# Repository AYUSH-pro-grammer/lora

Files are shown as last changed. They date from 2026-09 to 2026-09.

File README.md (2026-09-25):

# Lora

A LoRa board project that I made in order to figure out how radios really work, rather than just reading about them. It was a great way for me to do some PCB design and play around with KiCad, while learning what to do when things don’t go according to plan (which happened quite a bit).

# How its works

This board is a custom designed wireless communication module for long range applications. It is based on the dual-core Raspberry Pi RP2040 microcontroller and SX1262 LoRa transceiver.

- Power & Connectivity. 5V power and data thru USB-C port. An AP2112K-3.3 LDO regulator efficiently steps this down to a stable 3.3V for the system.

- Processing & Memory - The RP2040 is the brain. The RP2040 requires external memory, so it’s coupled with a W25Q16JV SPI Flash chip to store your firmware.

- Long-Range RF The SX1262 provides sub-GHz LoRa wireless communication. The RF path is controlled by a PE4259 RF switch and a Johanson Balun to condition the signal for the antenna.

- Internal Routing: The RP2040 uses its SPI busses to talk to the Flash memory and the SX1262 LoRa chip.

```text
[ USB-C ] ──5V──► [ AP2112K-3.3 LDO ] ──3.3V──┐
                                              ▼
[ W25Q16 Flash ] ◄──SPI── [ RP2040 ] ──SPI──► [ SX1262 LoRa ]
                        (Main Brain)                │
                                                    ▼
                                            [ PE4259 Switch ]
                                                    │
                                                    ▼
                                                [ Antenna ]
                                                    📡

```

# Images:

## 3d

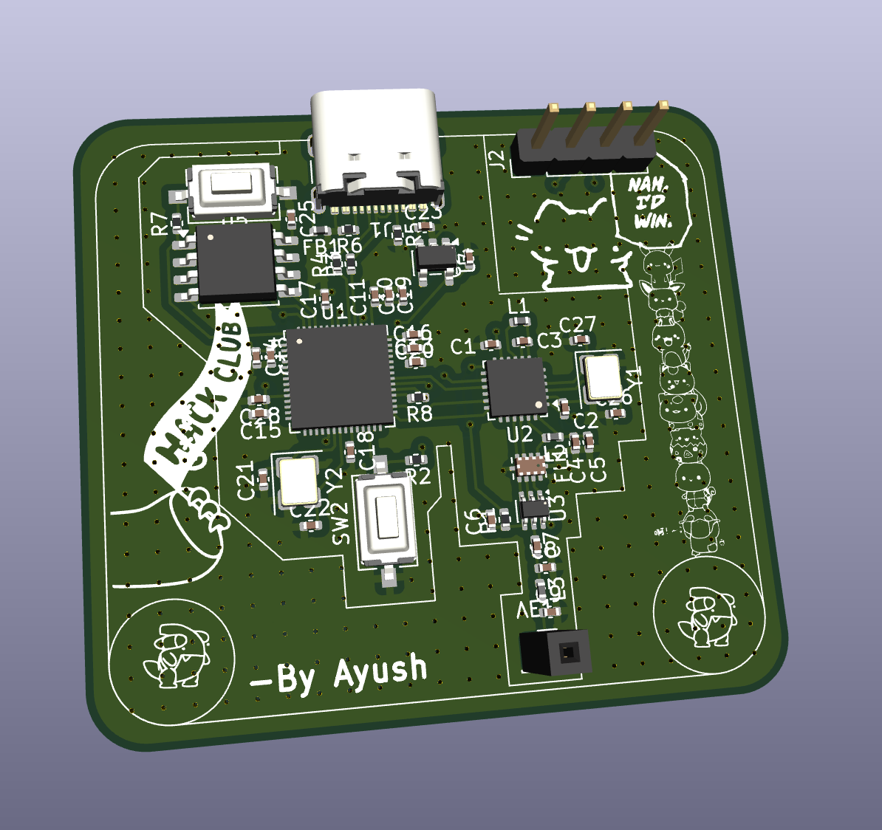
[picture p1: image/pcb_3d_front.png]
PCB 3D Front


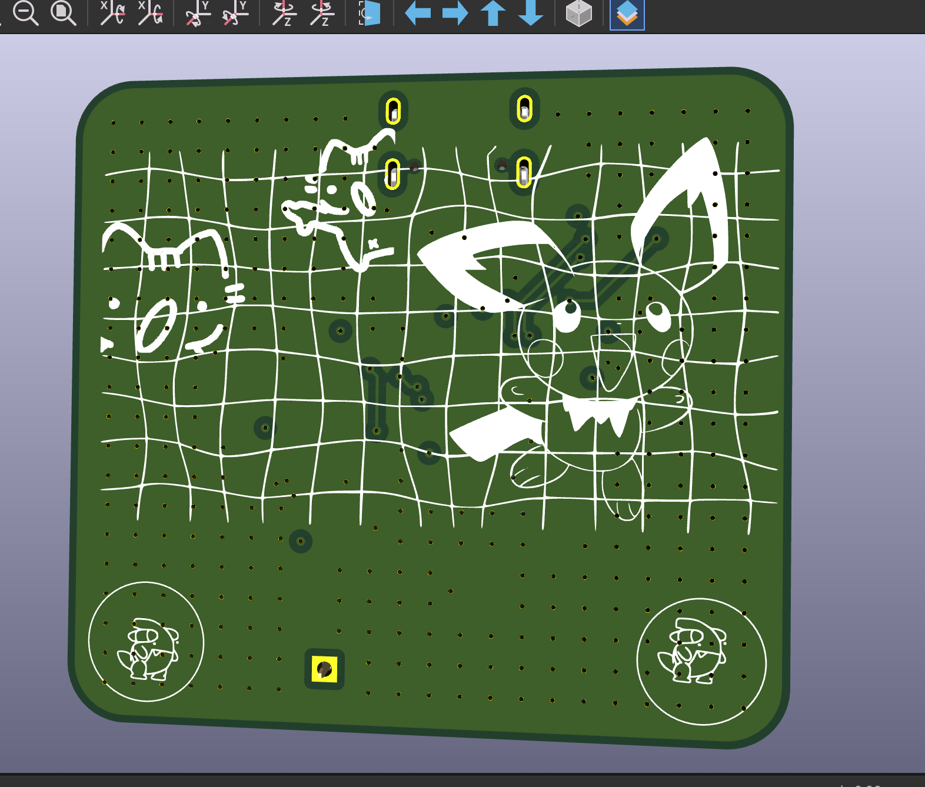
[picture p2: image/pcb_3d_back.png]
PCB 3D Back


## Schematic

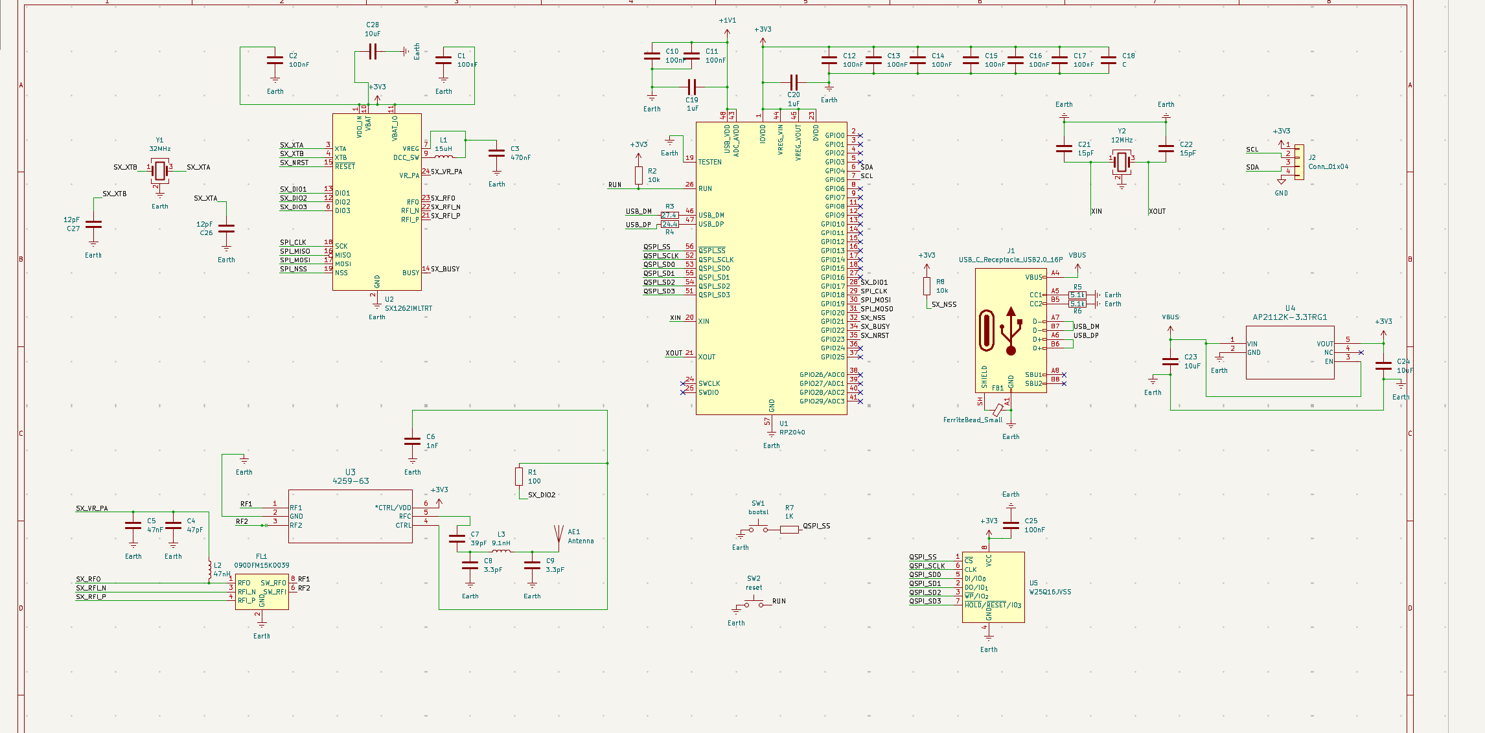
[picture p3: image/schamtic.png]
Schematic


## PCB 

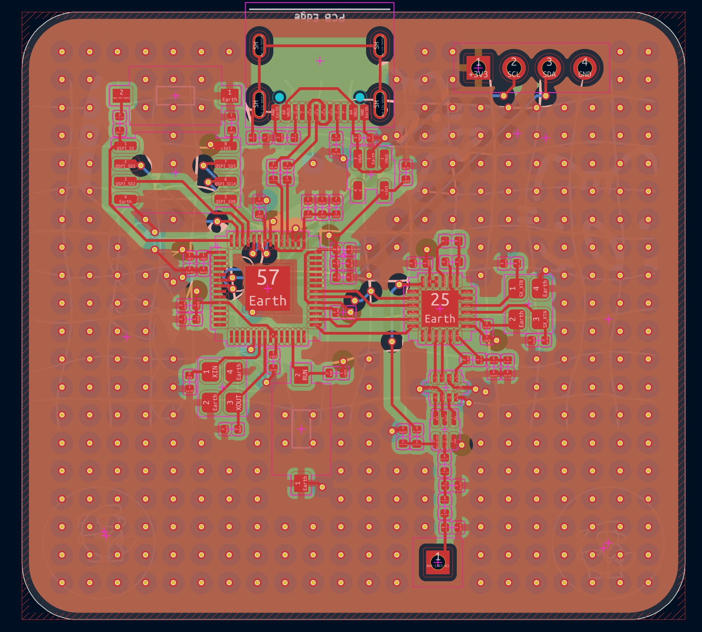
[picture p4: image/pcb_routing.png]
PCB Routing


## Components

Total Physical Components: 53
Capacitors: 28
Resistors: 8
Inductors: 3
Crystals/Oscillators: 2
Push Buttons (Cherry MX): 2
Antenna / Pin Headers: 2 (1 Spring Antenna + 1 Pin Header)
Ferrite Beads: 1
RF Baluns: 1
USB-C Connectors: 1
Voltage Regulators (AP2112K): 1
RF Switches (PE4259): 1
Flash Memory (W25Q16JV): 1
SX1262 LoRa IC: 1
RP2040 Microcontroller: 1

## BOM

|  Qty  | Component | Selected Part | Supplier  | Link | MOQ | Unit Price (USD) | Order Cost (USD) |
| :---: | :--- | :--- | :--- | :--- | --: | ---: | ---: |
| 1 | LoRa Spring Antenna | BW915SNX17-5W2 | LCSC | [Link](https://www.lcsc.com/product-detail/C496556.html) | 5 | $0.165 | $0.83 |
| 1 | Antenna Pin Header | 2.54-1×40P Pin Header | LCSC | [Link](https://www.lcsc.com/product-detail/C2337.html) | 5 | $0.159 | $0.80 |
| 12  | 100 nF Capacitor | 100 nF 16 V 0402 X7R | LCSC | [Link](https://www.lcsc.com/product-detail/C1525.html) | 100 | $0.005 | $0.46 |
| 1 | 150 pF Capacitor | 150 pF 50 V 0402 X7R | LCSC | [Link](https://www.lcsc.com/product-detail/C1527.html) | 100 | $0.004 | $0.43 |
| 1 | 20 pF Capacitor | 20 pF 50 V 0402 C0G | LCSC | [Link](https://www.lcsc.com/product-detail/C1554.html) | 100 | $0.007 | $0.69 |
| 1 | 220 pF Capacitor | 220 pF 50 V 0402 X7R | LCSC | [Link](https://www.lcsc.com/product-detail/C1530.html) | 100 | $0.003 | $0.25 |
| 1 | 1.8 pF Capacitor | 1.8 pF 50 V 0402 C0G | LCSC | [Link](https://www.lcsc.com/product-detail/C1553.html) | 100 | $0.005 | $0.50 |
| 2 | 15 pF Capacitor | 15 pF 50 V 0402 C0G | LCSC | [Link](https://www.lcsc.com/product-detail/C1548.html) | 100 | $0.004 | $0.36 |
| 2 | 12 pF Capacitor | 12 pF 50 V 0402 C0G | LCSC | [Link](https://www.lcsc.com/product-detail/C1547.html) | 100 | $0.006 | $0.60 |
| 2 | 1 pF Capacitor | 1 pF 50 V 0402 C0G | LCSC | [Link](https://www.lcsc.com/product-detail/C1550.html) | 100 | $0.003 | $0.27 |
| 3 | 160 pF Capacitor | 160 pF 50 V 0402 X7R | LCSC | [Link](https://www.lcsc.com/product-detail/C1528.html) | 100 | $0.005 | $0.51 |
| 2 | 1 µF Capacitor | 1 µF 16 V 0402 X5R | LCSC | [Link](https://www.lcsc.com/product-detail/C167339.html) |  50 | $0.015 | $0.73 |
| 1 | 1 nF Capacitor | 1 nF 50 V 0402 X7R | LCSC | [Link](https://www.lcsc.com/product-detail/C1523.html) | 100 | $0.005 | $0.51 |
| 1 | Ferrite Bead | 100 Ω @ 100 MHz 0402 | LCSC | [Link](https://www.lcsc.com/product-detail/C280601.html) |  20 | $0.006 | $0.12 |
| 1 | RF Balun | 0900FM15D0039E | LCSC | [Link](https://www.lcsc.com/product-detail/C1513363.html) | 1 | $1.214 | $1.21 |
| 1 | USB Type-C Connector | TYPE-C 16PIN SMD | LCSC | [Link](https://www.lcsc.com/product-detail/C2765186.html) |  20 | $0.071 | $1.43 |
| 1 | 15 nH Inductor | 15 nH ±3% 0402 | LCSC | [Link](https://www.lcsc.com/product-detail/C329619.html) |  10 | $0.041 | $0.41 |
| 1 | 47 nH Inductor | 47 nH ±2% 0402 | LCSC | [Link](https://www.lcsc.com/product-detail/C22334.html) |  10 | $0.064 | $0.64 |
| 1 | 9.1 nH Inductor | 9.1 nH ±2% 0402 | LCSC | [Link](https://www.lcsc.com/product-detail/C7516935.html) | 1 | $0.095 | $0.09 |
| 1 | 100 Ω Resistor | 100 Ω ±1% 0402 | LCSC | [Link](https://www.lcsc.com/product-detail/C25076.html) | 100 | $0.004 | $0.37 |
| 2 | 10 kΩ Resistor | 10 kΩ ±1% 0402 | LCSC | [Link](https://www.lcsc.com/product-detail/C25744.html) | 100 | $0.003 | $0.31 |
| 1 | 150 Ω Resistor | 150 Ω ±1% 0402 | LCSC | [Link](https://www.lcsc.com/product-detail/C25082.html) | 100 | $0.002 | $0.19 |
| 1 | 140 Ω Resistor | 140 Ω ±1% 0402 | LCSC | [Link](https://www.lcsc.com/product-detail/C25081.html) | 100 | $0.002 | $0.20 |
| 2 | 5.1 kΩ Resistor | 5.1 kΩ ±1% 0402 | LCSC | [Link](https://www.lcsc.com/product-detail/C25905.html) | 100 | $0.002 | $0.23 |
| 1 | 2.2 kΩ Resistor | 2.2 kΩ ±1% 0402 | LCSC | [Link](https://www.lcsc.com/product-detail/C25879.html) | 100 | $0.004 | $0.35 |
| 1 | Microcontroller | RP2040 (QFN-56) | LCSC | [Link](https://www.lcsc.com/product-detail/C2040.html) | 1 | $0.997 | $1.00 |
| 1 | LoRa Transceiver | SX1262IMLTRT (QFN-24) | LCSC | [Link](https://www.lcsc.com/product-detail/C191341.html) | 1 | $3.222 | $3.22 |
| 1 | RF Switch / LDO | LM337BTG | LCSC | [Link](https://www.lcsc.com/product-detail/C74415.html) | 1 | $0.673 | $0.67 |
| 1 | 3.3 V LDO Regulator | AP2112K-3.3TRG1 | LCSC | [Link](https://www.lcsc.com/product-detail/C51118.html) | 5 | $0.173 | $0.86 |
| 1 | SPI Flash Memory | W25Q16JVSSIQ (SOIC-8) | LCSC | [Link](https://www.lcsc.com/product-detail/C82317.html) | 1 | $1.023 | $1.02 |
| 1 | 32 MHz Crystal | X322532MMB4SI | LCSC | [Link](https://www.lcsc.com/product-detail/C113671.html) | 5 | $0.108 | $0.54 |
| 1 | 12 MHz Crystal | X322512MSB4SI | LCSC | [Link](https://www.lcsc.com/product-detail/C9002.html) | 5 | $0.096 | $0.48 |
| 2 | Tactile Switch | Cherry MX Clear (Pack of 10)  | StacksKB  | [Link](https://stackskb.com/store/cherry-mx-clear-switch-5-pin-pack-of-10/) |  10 | $0.480 | $4.80 |
| 1 | OLED Display | 0.96 Inch OLED Display Module | RoboCraze | [Link](https://robocraze.com/products/0-96in-oled-display-module-4pin) | 1 | $1.74 | $1.74 |
| **—** | **Total Procurement Cost (1st Batch Order)** | | | | | | **~$26.82** |

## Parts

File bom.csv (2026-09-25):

Quantity | Part Name | Link | Unit Price (USD) | Order Cost (USD)
1 | LoRa Spring Antenna BW915SNX17-5W2 (915MHz) | https://www.lcsc.com/product-detail/C496556.html | $0.165 | $0.83
1 | Antenna Pin (2.54mm Vertical Pin Header) | https://www.lcsc.com/product-detail/C2337.html | $0.159 | $0.80
11 | 100nF 16V 0402 Ceramic Capacitor | https://www.lcsc.com/product-detail/C1525.html | $0.005 | $0.46
1 | 150pF 50V 0402 Ceramic Capacitor | https://www.lcsc.com/product-detail/C1527.html | $0.004 | $0.43
1 | 20pF 50V 0402 Ceramic Capacitor | https://www.lcsc.com/product-detail/C1554.html | $0.007 | $0.69
1 | 220pF 50V 0402 Ceramic Capacitor | https://www.lcsc.com/product-detail/C1530.html | $0.003 | $0.25
1 | 1nF 50V 0402 Ceramic Capacitor | https://www.lcsc.com/product-detail/C1523.html | $0.005 | $0.51
1 | 1.8pF 50V 0402 Ceramic Capacitor | https://www.lcsc.com/product-detail/C1553.html | $0.005 | $0.50
2 | 15pF 50V 0402 Ceramic Capacitor | https://www.lcsc.com/product-detail/C1548.html | $0.004 | $0.36
1 | Capacitor C18 (Placeholder 100nF 0402) | https://www.lcsc.com/product-detail/C1525.html | $0.005 | $0.00
2 | 1uF 16V 0402 Ceramic Capacitor | https://www.lcsc.com/product-detail/C167339.html | $0.015 | $0.73
2 | 1pF 50V 0402 Ceramic Capacitor | https://www.lcsc.com/product-detail/C1550.html | $0.003 | $0.27
2 | 12pF 50V 0402 Ceramic Capacitor | https://www.lcsc.com/product-detail/C1547.html | $0.006 | $0.60
3 | 160pF 50V 0402 Ceramic Capacitor | https://www.lcsc.com/product-detail/C1528.html | $0.005 | $0.51
1 | 100 Ohm 0402 Ferrite Bead | https://www.lcsc.com/product-detail/C280601.html | $0.006 | $0.12
1 | Johanson 0900FM15D0039E RF Balun | https://www.lcsc.com/product-detail/C1513363.html | $1.214 | $1.21
1 | USB Type-C 16-Pin Connector (SHOU HAN) | https://www.lcsc.com/product-detail/C2765186.html | $0.071 | $1.43
1 | 15nH 0402 SMD Inductor | https://www.lcsc.com/product-detail/C329619.html | $0.041 | $0.41
1 | 47nH 0402 SMD Inductor | https://www.lcsc.com/product-detail/C22334.html | $0.064 | $0.64
1 | 9.1nH 0402 SMD Inductor | https://www.lcsc.com/product-detail/C7516935.html | $0.095 | $0.09
1 | 100 Ohm 1% 0402 Resistor | https://www.lcsc.com/product-detail/C25076.html | $0.004 | $0.37
2 | 10k Ohm 1% 0402 Resistor | https://www.lcsc.com/product-detail/C25744.html | $0.003 | $0.31
1 | 150 Ohm 1% 0402 Resistor | https://www.lcsc.com/product-detail/C25082.html | $0.002 | $0.19
1 | 140 Ohm 1% 0402 Resistor | https://www.lcsc.com/product-detail/C25081.html | $0.002 | $0.20
2 | 5.1k Ohm 1% 0402 Resistor | https://www.lcsc.com/product-detail/C25905.html | $0.002 | $0.23
1 | 2.2k Ohm 1% 0402 Resistor | https://www.lcsc.com/product-detail/C25879.html | $0.004 | $0.35
2 | Cherry MX Clear Tactile Switch (5-pin) | https://stackskb.com/store/cherry-mx-clear-switch-5-pin-pack-of-10/ | $0.480 | $4.80
1 | RP2040 Microcontroller | https://www.lcsc.com/product-detail/C2040.html | $0.997 | $1.00
1 | SX1262IMLTRT LoRa Transceiver | https://www.lcsc.com/product-detail/C191341.html | $3.222 | $3.22
1 | PE4259-63 RF Switch (SOT-363) | https://www.lcsc.com/product-detail/C74415.html | $0.673 | $0.67
1 | AP2112K-3.3TRG1 LDO Regulator | https://www.lcsc.com/product-detail/C51118.html | $0.173 | $0.86
1 | W25Q16JVSSIQ SPI Flash Memory | https://www.lcsc.com/product-detail/C82317.html | $1.023 | $1.02
1 | 32MHz 3225 4-pin SMD Crystal | https://www.lcsc.com/product-detail/C113671.html | $0.108 | $0.54
1 | 12MHz 3225 4-pin SMD Crystal (RP2040 Target) | https://www.lcsc.com/product-detail/C9002.html | $0.096 | $0.48$
1 | 0.96 Inch OLED Display Module | https://robocraze.com/products/0-96in-oled-display-module-4pin?variant=40192586645657 | $1.74 | $1.74

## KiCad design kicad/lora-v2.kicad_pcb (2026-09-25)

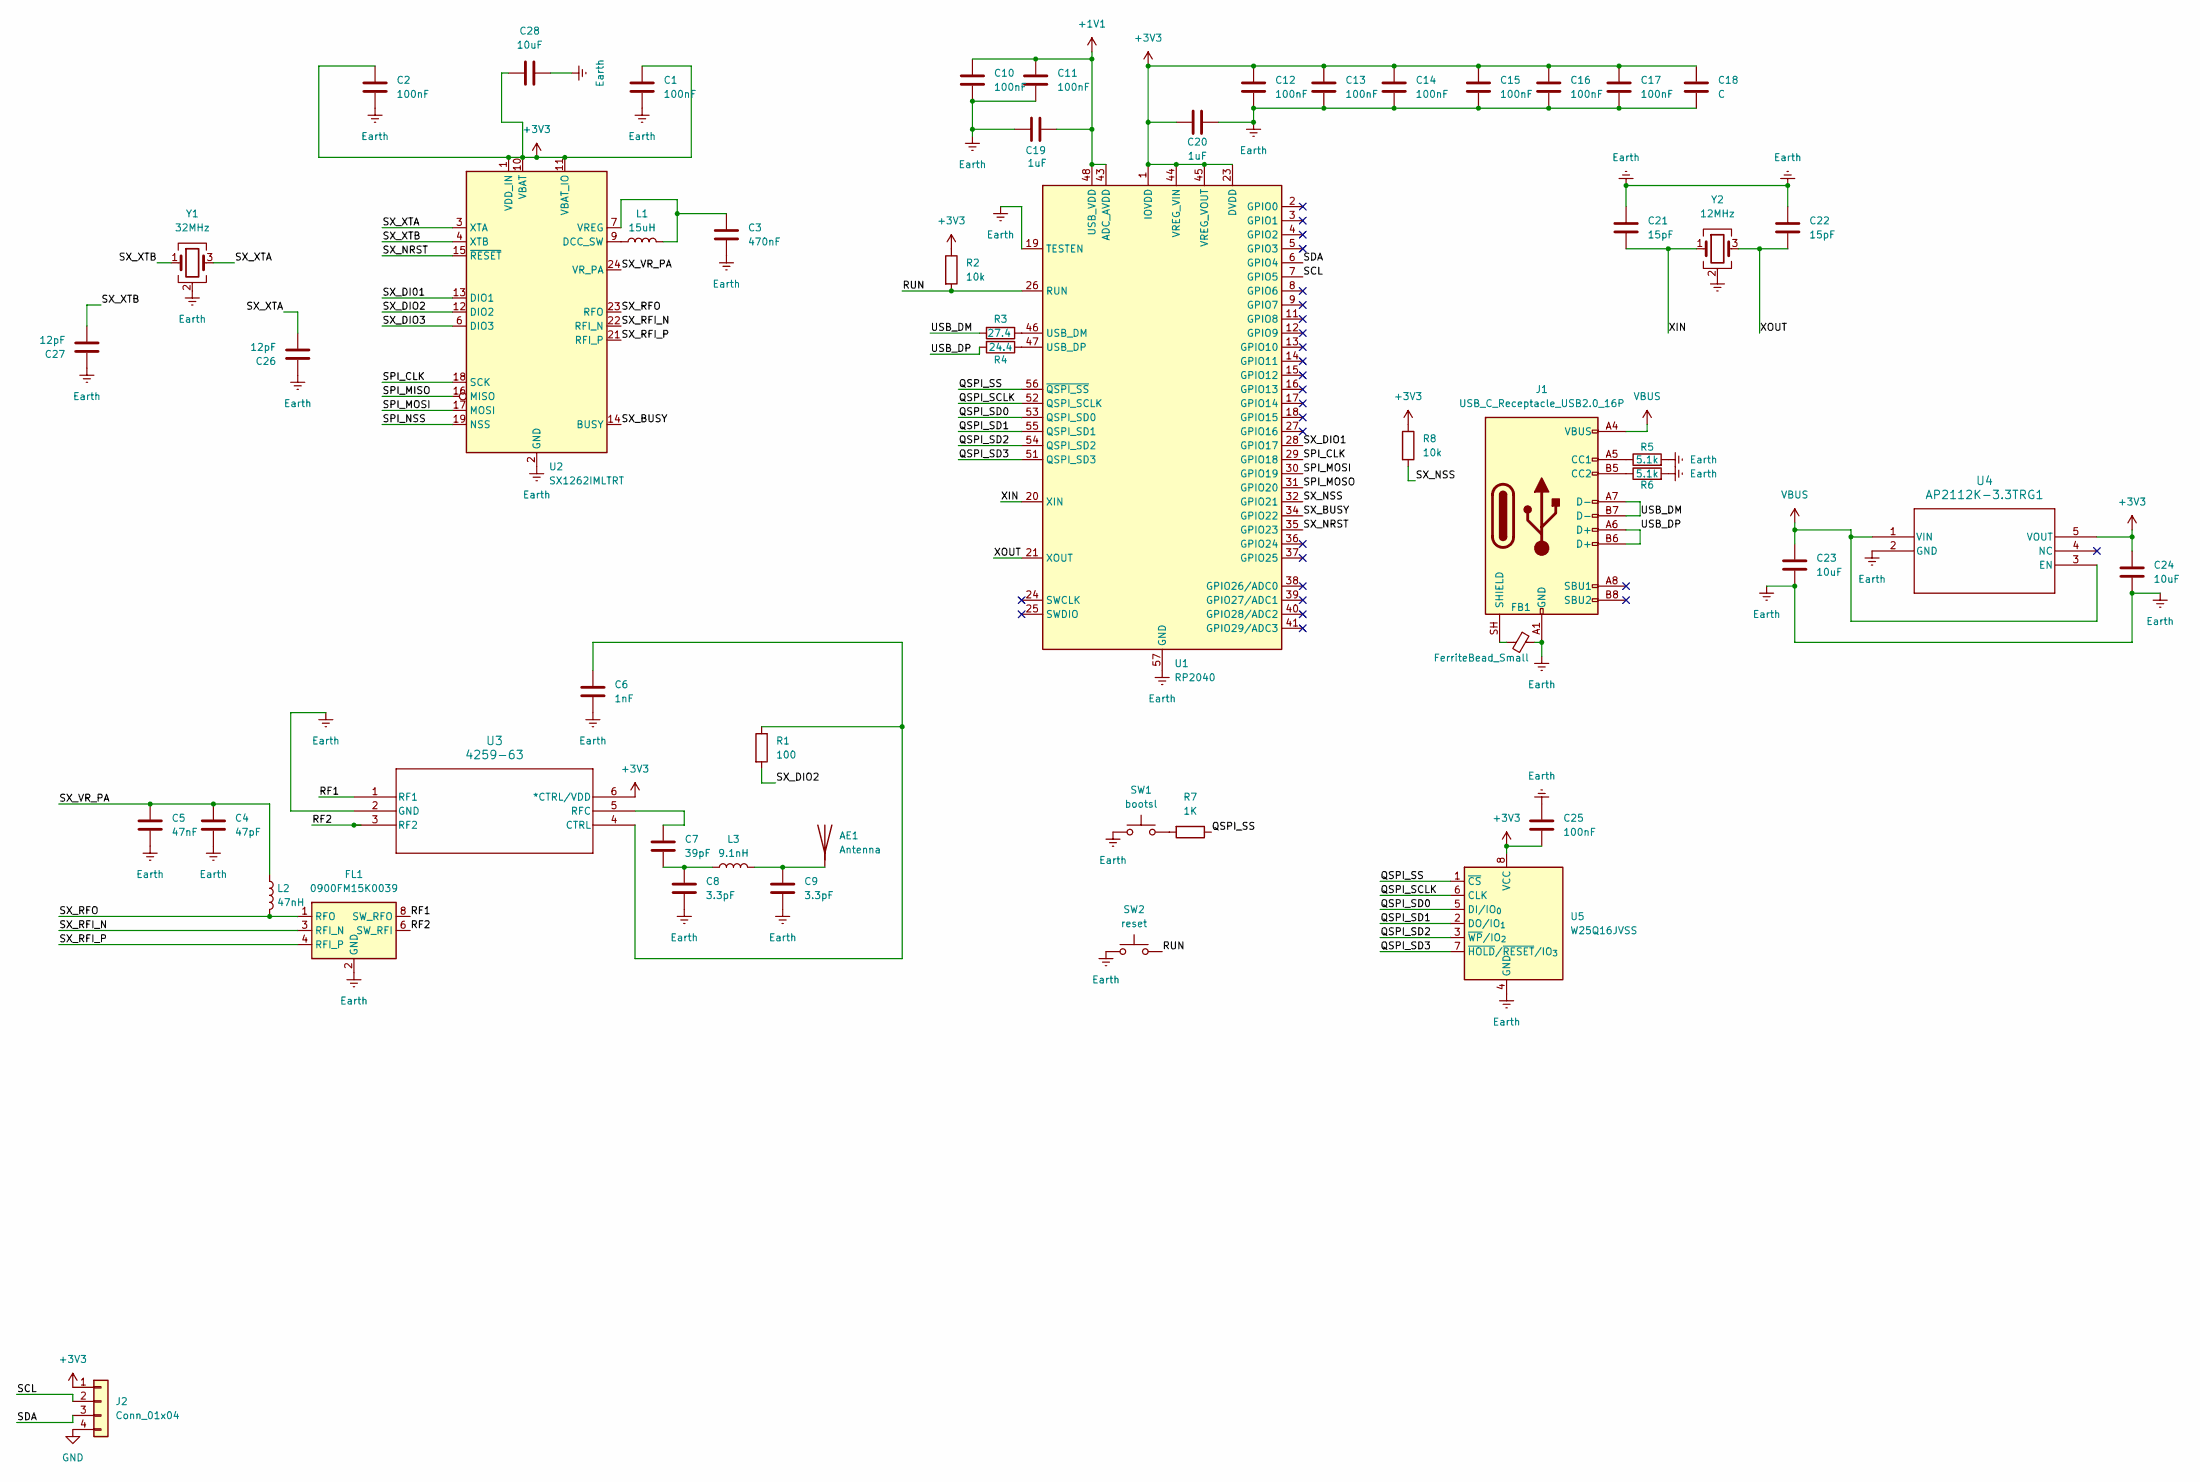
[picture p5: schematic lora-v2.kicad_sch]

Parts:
AE1: Antenna; PinSocket_1x01_P2.54mm_Vertical
C1, C2, C10, C11, C12, C13, C14, C15, C16, C17, C25: 100nF; C_0402_1005Metric
C3: 470nF; C_0402_1005Metric
C4: 47pF; C_0402_1005Metric
C5: 47nF; C_0402_1005Metric
C6: 1nF; C_0402_1005Metric
C7: 39pF; C_0402_1005Metric
C8, C9: 3.3pF; C_0402_1005Metric
C18: C; C_0402_1005Metric
C19, C20: 1uF; C_0402_1005Metric
C21, C22: 15pF; C_0402_1005Metric
C23, C24, C28: 10uF; C_0402_1005Metric
C26, C27: 12pF; C_0402_1005Metric
FB1: FerriteBead_Small; L_0402_1005Metric
FL1: 0900FM15K0039; Balun_Johanson_0900FM15K0039
J1: USB_C_Receptacle_USB2.0_16P; USB_C_Receptacle_GCT_USB4105-xx-A_16P_TopMnt_Horizontal
J2: Conn_01x04; PinHeader_1x04_P2.54mm_Vertical
L1: 15uH; L_0402_1005Metric
L2: 47nH; L_0402_1005Metric
L3: 9.1nH; L_0402_1005Metric
R1: 100; R_0402_1005Metric
R2, R8: 10k; R_0402_1005Metric
R3: 27.4; R_0402_1005Metric
R4: 24.4; R_0402_1005Metric
R5, R6: 5.1k; R_0402_1005Metric
R7: 1K; R_0402_1005Metric
SW1: bootsl; SW_Tactile_SPST_NO_Straight_CK_PTS636Sx25SMTRLFS
SW2: reset; SW_Tactile_SPST_NO_Straight_CK_PTS636Sx25SMTRLFS
U1: RP2040; QFN-56-1EP_7x7mm_P0.4mm_EP3.2x3.2mm
U2: SX1262IMLTRT; QFN-24-1EP_4x4mm_P0.5mm_EP2.6x2.6mm
U3: 4259-63; SOT-363_SC-70-6
U4: AP2112K-3.3TRG1; SOT-23-5
U5: W25Q16JVSS; SOIC-8_5.3x5.3mm_P1.27mm
Y1: 32MHz; Crystal_SMD_3225-4Pin_3.2x2.5mm
Y2: 12MHz; Crystal_SMD_Abracon_ABM8G-4Pin_3.2x2.5mm

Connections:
+1V1: C10.1, C11.1, C19.2, U1.43 (ADC_AVDD), U1.48 (USB_VDD)
+3V3: C1.1, C2.1, C12.1, C13.1, C14.1, C15.1, C16.1, C17.1, C18.1, C20.2, C24.1, C25.2, C28.1, J2.1, R2.1, R8.1, U1.1 (IOVDD), U1.10 (IOVDD), U1.22 (IOVDD), U1.23 (DVDD), U1.33 (IOVDD), U1.42 (IOVDD), U1.44 (VREG_VIN), U1.45 (VREG_VOUT), U1.49 (IOVDD), U1.50 (DVDD), U2.1 (VDD_IN), U2.10 (VBAT), U2.11 (VBAT_IO), U3.6 (*CTRL/VDD), U4.5 (VOUT), U5.8 (VCC)
/QSPI_SCLK: U1.52 (QSPI_SCLK), U5.6 (CLK)
/QSPI_SD0: U1.53 (QSPI_SD0), U5.5 (DI/IO_{0})
/QSPI_SD1: U1.55 (QSPI_SD1), U5.2 (DO/IO_{1})
/QSPI_SD2: U1.54 (QSPI_SD2), U5.3 (~WP/IO_{2})
/QSPI_SD3: U1.51 (QSPI_SD3), U5.7 (~HOLD/~RESET/IO_{3})
/QSPI_SS: R7.1, U1.56 (~QSPI_SS), U5.1 (~CS)
/RF1: FL1.8 (SW_RFO), U3.1 (RF1)
/RF2: FL1.6 (SW_RFI), U3.3 (RF2)
/RUN: R2.2, SW2.2, U1.26 (RUN)
/SCL: J2.2, U1.7 (GPIO5)
/SDA: J2.3, U1.6 (GPIO4)
/SPI_CLK: U1.29 (GPIO18), U2.18 (SCK)
/SPI_MISO: U2.16 (MISO)
/SPI_MOSI: U1.30 (GPIO19), U2.17 (MOSI)
/SPI_MOSO: U1.31 (GPIO20)
/SPI_NSS: U2.19 (NSS)
/SX_BUSY: U1.34 (GPIO22), U2.14 (BUSY)
/SX_DI01: U2.13 (DIO1)
/SX_DIO1: U1.28 (GPIO17)
/SX_DIO2: R1.2, U2.12 (DIO2)
/SX_DIO3: U2.6 (DIO3)
/SX_NRST: U1.35 (GPIO23), U2.15 (~RESET)
/SX_NSS: R8.2, U1.32 (GPIO21)
/SX_RFI_N: FL1.3 (RFI_N), U2.22 (RFI_N)
/SX_RFI_P: FL1.4 (RFI_P), U2.21 (RFI_P)
/SX_RFO: FL1.1 (RFO), L2.2, U2.23 (RFO)
/SX_VR_PA: C4.1, C5.1, L2.1, U2.24 (VR_PA)
/SX_XTA: C26.2, U2.3 (XTA), Y1.3
/SX_XTB: C27.2, U2.4 (XTB), Y1.1
/USB_DM: J1.A7 (D-), J1.B7 (D-), R3.2
/USB_DP: J1.A6 (D+), J1.B6 (D+), R4.2
/XIN: C21.2, U1.20 (XIN), Y2.1
/XOUT: C22.2, U1.21 (XOUT), Y2.3
Earth: C1.2, C2.2, C3.2, C4.2, C5.2, C6.2, C8.2, C9.2, C10.2, C11.2, C12.2, C13.2, C14.2, C15.2, C16.2, C17.2, C18.2, C19.1, C20.1, C21.1, C22.1, C23.2, C24.2, C25.1, C26.1, C27.1, C28.2, FB1.1, FL1.2 (GND), FL1.5 (GND), FL1.7 (GND), FL1.9 (GND), FL1.10 (GND), J1.A1 (GND), J1.A12 (GND), J1.B1 (GND), J1.B12 (GND), R5.2, R6.2, SW1.1, SW2.1, U1.19 (TESTEN), U1.57 (GND), U2.2 (GND), U2.5 (GND), U2.8 (GND), U2.20 (GND), U2.25 (GND), U3.2 (GND), U4.2 (GND), U5.4 (GND), Y1.2 (G), Y1.4 (G), Y2.2 (G), Y2.4 (G)
GND: J2.4
unnamed: AE1.1 (A_1), C9.1, L3.2
unnamed: C7.2, C8.1, L3.1
unnamed: J1.A5 (CC1), R5.1
unnamed: J1.B5 (CC2), R6.1
unnamed: FB1.2, J1.SH (SHIELD)
unnamed: R7.2, SW1.2
unnamed: R3.1, U1.46 (USB_DM)
unnamed: R4.1, U1.47 (USB_DP)
unnamed: L1.1, U2.9 (DCC_SW)
unnamed: C3.1, L1.2, U2.7 (VREG)
unnamed: C6.1, R1.1, U3.4 (CTRL)
unnamed: C7.1, U3.5 (RFC)
VBUS: C23.1, J1.A4 (VBUS), J1.A9 (VBUS), J1.B4 (VBUS), J1.B9 (VBUS), U4.1 (VIN), U4.3 (EN)

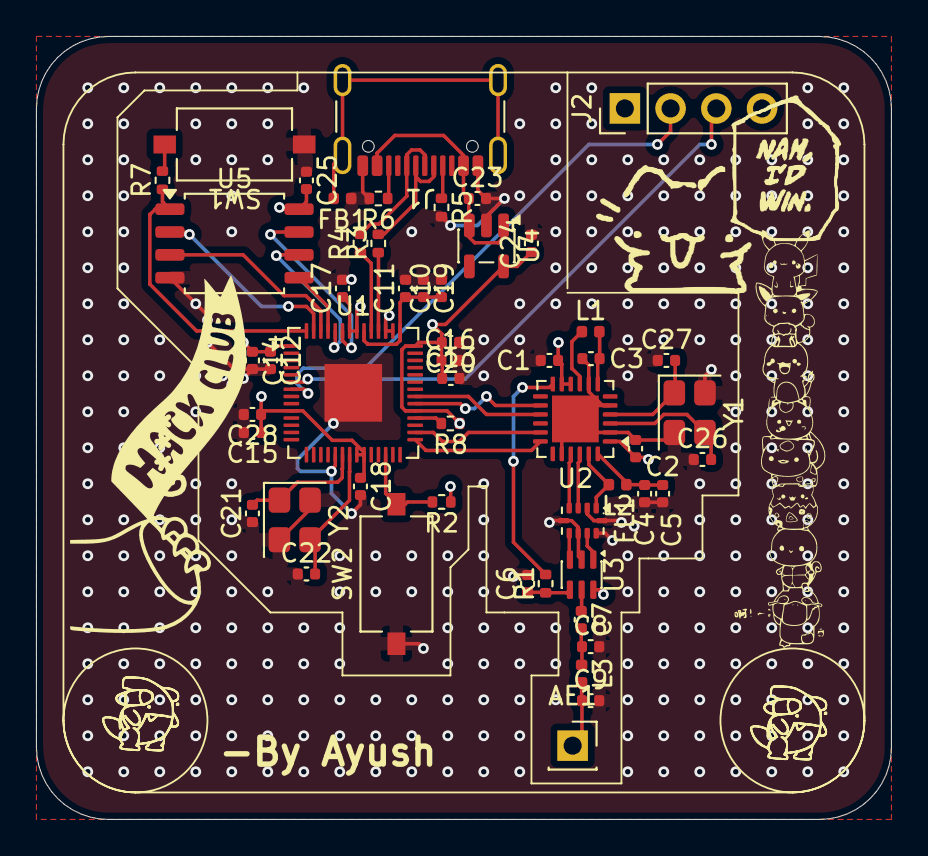
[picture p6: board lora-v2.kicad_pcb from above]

Board: 4 copper layers, 47.5 x 43.5 mm, 53 parts (0 on the bottom side), 43 nets.

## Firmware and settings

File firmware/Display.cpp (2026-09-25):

#include "Display.h"

#include <Wire.h>
#include <Adafruit_GFX.h>
#include <Adafruit_SSD1306.h>


#define OLED_WIDTH   128
#define OLED_HEIGHT   32
#define OLED_ADDRESS 0x3C


#define OLED_SDA 4
#define OLED_SCL 5

Adafruit_SSD1306 display(
    OLED_WIDTH,
    OLED_HEIGHT,
    &Wire,
    -1
);


void displayInit() {


    Wire.setSDA(OLED_SDA);
    Wire.setSCL(OLED_SCL);

    Wire.begin();

    if (!display.begin(
            SSD1306_SWITCHCAPVCC,
            OLED_ADDRESS)) {

        return;
    }

    display.clearDisplay();

    display.setTextColor(SSD1306_WHITE);

    display.setTextSize(1);

    display.setCursor(0, 0);
    display.println("LORA NODE");

    display.setCursor(0, 12);
    display.println("Display OK");

    display.display();

    delay(1000);
}


void displayStatus(const char* line1, const char* line2) {

    display.clearDisplay();

    display.setTextColor(SSD1306_WHITE);
    display.setTextSize(1);

    display.setCursor(0, 0);
    display.println("LORA NODE");

    display.setCursor(0, 12);
    display.println(line1);

    if (line2 != nullptr) {
        display.setCursor(0, 22);
        display.println(line2);
    }

    display.display();
}


void displayTx(unsigned long packetNumber) {

    display.clearDisplay();

    display.setTextColor(SSD1306_WHITE);
    display.setTextSize(1);

    display.setCursor(0, 0);
    display.println("LORA NODE");

    display.setCursor(0, 12);
    display.println("TRANSMITTING...");

    display.setCursor(0, 22);
    display.print("PACKET #");
    display.println(packetNumber);

    display.display();
}


void displayTxSuccess(
    unsigned long packetNumber,
    unsigned long duration) {

    display.clearDisplay();

    display.setTextColor(SSD1306_WHITE);
    display.setTextSize(1);

    display.setCursor(0, 0);
    display.println("LORA NODE");

    display.setCursor(0, 12);
    display.println("TX SUCCESS");

    display.setCursor(0, 22);
    display.print("#");
    display.print(packetNumber);

    display.print("  ");
    display.print(duration);
    display.println("ms");

    display.display();
}


void displayError(int errorCode) {

    display.clearDisplay();

    display.setTextColor(SSD1306_WHITE);
    display.setTextSize(1);

    display.setCursor(0, 0);
    display.println("LORA NODE");

    display.setCursor(0, 12);
    display.println("TX ERROR");

    display.setCursor(0, 22);
    display.print("CODE: ");
    display.println(errorCode);

    display.display();
}

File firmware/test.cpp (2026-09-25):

#include <Arduino.h>
#include <SPI.h>
#include <RadioLib.h>

#include "Display.h"

#define PIN_LORA_SCK    18
#define PIN_LORA_MOSI   19
#define PIN_LORA_MISO   20
#define PIN_LORA_NSS    21
#define PIN_LORA_BUSY   22 
#define PIN_LORA_NRST   23 
#define PIN_LORA_DIO1   16 

#define RF_FREQUENCY    915.0 
#define RF_BANDWIDTH    125.0   
#define RF_SPREADING    7       
#define RF_CODING_RATE  5 
#define RF_OUTPUT_POWER 14    
#define RF_PREAMBLE_LEN 8     


SX1262 radio = new Module(PIN_LORA_NSS, PIN_LORA_DIO1, PIN_LORA_NRST, PIN_LORA_BUSY);

uint32_t packetCounter = 0;

void setup() {

  Serial.begin(115200);

  while (!Serial && millis() < 3000);

  Serial.println("\n==========================================");
  Serial.println("   RP2040 + SX1262 LoRa Setting Up Test   ");
  Serial.println("==========================================");


  displayInit();

  displayStatus("BOOTING...", "Please wait");




  SPI.setSCK(PIN_LORA_SCK);
  SPI.setTX(PIN_LORA_MOSI);
  SPI.setRX(PIN_LORA_MISO);

  SPI.begin();



  displayStatus("LORA", "Initializing...");

  Serial.print("[SX1262] Initializing transceiver... ");


  int state = radio.begin(
    RF_FREQUENCY,
    RF_BANDWIDTH,
    RF_SPREADING,
    RF_CODING_RATE,
    RADIOLIB_SX126X_SYNC_WORD_PRIVATE,
    RF_OUTPUT_POWER,
    RF_PREAMBLE_LEN
  );


  if (state == RADIOLIB_ERR_NONE) {

    Serial.println("SUCCESS!");

    displayStatus("LORA READY", "Starting TX...");

    delay(1000);

  } else {

    Serial.print("FAILED, error code: ");
    Serial.println(state);

    displayError(state);

    Serial.println(
      "Check SPI connections, 32MHz crystal, and 3.3V power rails."
    );

    while (true) {
      delay(1000);
    }
  }

  if (radio.setDio2AsRfSwitch(true) != RADIOLIB_ERR_NONE) {

    Serial.println(
      "[SX1262] Warning: Failed to configure DIO2 as RF Switch control."
    );

    displayStatus("WARNING", "RF switch error");

    delay(1000);

  } else {

    Serial.println(
      "[SX1262] RF Switch (DIO2) control enabled."
    );
  }


  Serial.println(
    "[SX1262] Setup complete. Starting TX loop...\n"
  );

  displayStatus("RUNNING", "LoRa TX ready");

  delay(1000);
}




void loop() {

  char payload[32];

  snprintf(
    payload,
    sizeof(payload),
    "PING #%lu",
    (unsigned long)packetCounter
  );



  displayTx(packetCounter);


  Serial.print("[SX1262] Transmitting packet: \"");
  Serial.print(payload);
  Serial.print("\"... ");


  unsigned long startTime = millis();

  int state = radio.transmit(payload);

  unsigned long duration = millis() - startTime;



  if (state == RADIOLIB_ERR_NONE) {

    Serial.print("SENT! (");
    Serial.print(duration);
    Serial.print(" ms) | Data Rate: ");
    Serial.print(radio.getDataRate());
    Serial.println(" bps");


    displayTxSuccess(
      packetCounter,
      duration
    );


  } else if (state == RADIOLIB_ERR_PACKET_TOO_LONG) {

    Serial.println("FAILED: Packet too long.");

    displayStatus(
      "TX FAILED",
      "Packet too long"
    );


  } else if (state == RADIOLIB_ERR_TX_TIMEOUT) {

    Serial.println("FAILED: Transmission timed out.");

    displayStatus(
      "TX FAILED",
      "Timeout"
    );


  } else {

    Serial.print("FAILED: Error code ");
    Serial.println(state);

    displayError(state);
  }


  packetCounter++;

  delay(3000);
}
